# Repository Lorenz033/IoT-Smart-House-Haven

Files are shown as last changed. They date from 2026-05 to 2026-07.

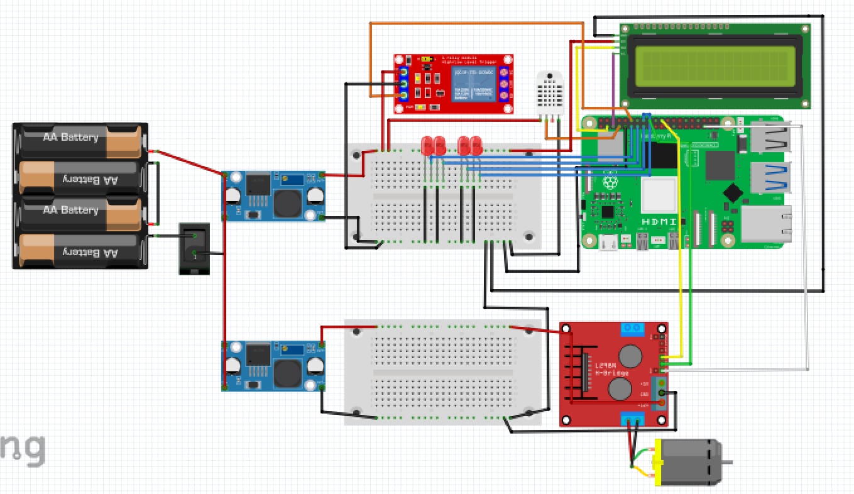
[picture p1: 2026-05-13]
schematic/d1bb4838-2788-41eb-9520-5f88e29ecf18.jpg

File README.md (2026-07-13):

# 📘 Smart Haven IoT System (Raspberry Pi + MQTT + MVC)

## 🧠 Overview

Smart Haven is an IoT-based automation system built using:

- Raspberry Pi 5
- MQTT communication
- Node-RED Dashboard
- Face Recognition (OpenCV + face_recognition)
- Voice Recognition (Vosk)
- LCD Display (I2C)
- GPIO Relay Control
- DC Motor Control (L298N + PWM)
- MVC software architecture

The system supports:
- Smart door access (face + voice authentication)
- Relay control (lock/unlock)
- DC motor speed control via Node-RED slider
- Scenario-based automation (Welcome / Leaving mode)

## Hardware pinout

All GPIO numbers below use **BCM numbering** (`GPIO.setmode(GPIO.BCM)`). The
physical-pin column refers to the Raspberry Pi's 40-pin header.

| Device / signal | BCM GPIO | Physical header pin | Direction / notes |
|---|---:|---:|---|
| DHT22 data | GPIO 4 | 7 | Input; temperature and humidity sensor |
| LED DO1 | GPIO 17 | 11 | Output |
| LED DO2 | GPIO 27 | 13 | Output |
| LED DO3 | GPIO 22 | 15 | Output |
| LED DO4 | GPIO 23 | 16 | Output |
| Relay / door lock control | GPIO 18 | 12 | Output; HIGH = unlock, LOW = lock |
| MG90S door-servo signal | GPIO 19 | 35 | PWM output |
| LED DO5 | GPIO 16 | 36 | Output |
| LED DO6 | GPIO 20 | 38 | Output |
| LED DO7 | GPIO 12 | 32 | Output |
| LED DO8 | GPIO 21 | 40 | Output |
| Flame-sensor digital output | GPIO 24 | 18 | Input; active LOW with internal pull-up |
| Smoke-sensor digital output | GPIO 26 | 37 | Input; active LOW with internal pull-up |
| Buzzer control | GPIO 25 | 22 | Output |
| L298N motor enable (ENA) | GPIO 13 | 33 | PWM output at 1 kHz |
| L298N motor direction (IN1) | GPIO 5 | 29 | Output |
| L298N motor direction (IN2) | GPIO 6 | 31 | Output |
| LCD I²C SDA | GPIO 2 / SDA1 | 3 | I²C bus 1 |
| LCD I²C SCL | GPIO 3 / SCL1 | 5 | I²C bus 1 |

The LCD is configured as a 16×2 PCF8574 I²C display at address `0x27` on I²C
bus 1. Connect each module's power and ground pins to a suitable supply and a
common Raspberry Pi ground. Do not power motors or a servo directly from a Pi
GPIO or 5 V rail unless the power budget has been verified; use an appropriate
external supply and retain the common ground.

---

Node-RED Dashboard
↓
MQTT Broker
↓
App Controller (Brain)
↓
────────────────────────
| Scenario Logic |
| Services Layer |
| Model (State) |
| View (LCD Display) |
────────────────────────
↓
Raspberry Pi GPIO / PWM

⚙️ Features
🔐 Smart Door System
Face recognition authentication
Voice command activation ("open")
Automatic unlock/lock via relay
📺 LCD Feedback
System status display
Welcome / Goodbye messages
Real-time feedback
📡 MQTT Communication
Topic	Function
WSA2025/DI1	Scenario trigger button
WSA2025/RELAY01	Manual relay control
WSA2025/MOTOR01	DC motor speed control

DC motor buttons should publish to `WSA2025/MOTOR01`:
- `50` for 50 percent speed
- `75` for 75 percent speed
- `100` for 100 percent speed
- `OFF` to stop the motor

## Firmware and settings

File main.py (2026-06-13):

# main.py
from services.mqtt_service import MQTTService
from services.gpio_service import GPIOService
from view.lcd_view import LCDView
from services.vision_service import VisionService
from services.voice_service import VoiceService
from services.sensor_service import SensorService
from model.environment_model import EnvironmentModel
from controller.app_controller import AppController

BROKER = "localhost"
PORT = 1883

TOPIC_DI1 = "WSA2025/DI1"
TOPIC_RELAY = "WSA2025/RELAY01"
TOPIC_DO1 = "WSA2025/DO1"
TOPIC_DO2 = "WSA2025/DO2"
TOPIC_DO3 = "WSA2025/DO3"
TOPIC_DO4 = "WSA2025/DO4"
TOPIC_DO5 = "WSA2025/DO5"
TOPIC_DO6 = "WSA2025/DO6"
TOPIC_DO7 = "WSA2025/DO7"
TOPIC_DO8 = "WSA2025/DO8"
TOPIC_MOTOR = "WSA2025/MOTOR01"
TOPIC_BUZZER = "WSA2025/BUZZER01"
TOPIC_DOOR = "WSA2025/DOOR01"
TOPIC_FIRE_STATUS = "WSA2025/FIRE_STATUS"
TOPIC_SMOKE_STATUS = "WSA2025/SMOKE_STATUS"



sensor = SensorService(pin=4)
environment = EnvironmentModel()

# =========================
# INIT COMPONENTS
# =========================
mqtt_service = MQTTService(BROKER, PORT)

gpio = GPIOService(
    pin=18,
    flame_pin=24,
    smoke_pin=26,
    buzzer_pin=25,
    servo_pin=19,
    flame_active_low=True,
    smoke_active_low=True
)

lcd = LCDView()

vision = VisionService(
    "/home/lorenz/iothings/models/manny.pkl"
)

# 🔥 FIX: NO mic_index anymore (auto-detect inside service)
voice = VoiceService(
    "/home/lorenz/iothings/models/vosk-model-small-en-us-0.15"
)

controller = AppController(
    mqtt_service.client,
    gpio,
    lcd,
    vision,
    voice,
    sensor,
    environment 
)


client = mqtt_service.connect(
    on_connect=lambda c, u, f, rc: c.subscribe([
        (TOPIC_DI1, 0),
        (TOPIC_RELAY, 0),
        (TOPIC_DO1, 0),
        (TOPIC_DO2, 0),
        (TOPIC_DO3, 0),
        (TOPIC_DO4, 0),
        (TOPIC_DO5, 0),
        (TOPIC_DO6, 0),
        (TOPIC_DO7, 0),
        (TOPIC_DO8, 0),
        (TOPIC_MOTOR, 0),
        (TOPIC_BUZZER, 0),
        (TOPIC_DOOR, 0)
    ]),
    on_message=controller.on_message,
    on_disconnect=lambda c, u, rc: print("Disconnected")
)

print("System running...")
client.loop_forever()

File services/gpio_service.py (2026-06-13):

import RPi.GPIO as GPIO
from gpiozero import AngularServo

class GPIOService:

    def __init__(
        self,
        pin=18,
        flame_pin=24,
        smoke_pin=26,
        buzzer_pin=25,
        servo_pin=19,
        flame_active_low=True,
        smoke_active_low=True
    ):

  
        self.pin = pin
        self.flame_pin = flame_pin
        self.smoke_pin = smoke_pin
        self.buzzer_pin = buzzer_pin
        self.servo_pin = servo_pin
        self.flame_active_low = flame_active_low
        self.smoke_active_low = smoke_active_low
        self.motor_speed = 0

  
        self.leds = {
            "DO1": 17,
            "DO2": 27,
            "DO3": 22,
            "DO4": 23,
            "DO5": 16,
            "DO6": 20,
            "DO7": 12,
            "DO8": 21
        }

        self.motor = {
            "ENA": 13,
            "IN1": 5,
            "IN2": 6
        }

        GPIO.setwarnings(False)
        GPIO.setmode(GPIO.BCM)

        # Relay
        GPIO.setup(self.pin, GPIO.OUT)
        GPIO.output(self.pin, GPIO.HIGH)

        # Flame sensor and buzzer
        flame_pull_mode = GPIO.PUD_UP if self.flame_active_low else GPIO.PUD_DOWN
        GPIO.setup(self.flame_pin, GPIO.IN, pull_up_down=flame_pull_mode)

        # Smoke sensor
        smoke_pull_mode = GPIO.PUD_UP if self.smoke_active_low else GPIO.PUD_DOWN
        GPIO.setup(self.smoke_pin, GPIO.IN, pull_up_down=smoke_pull_mode)

        GPIO.setup(self.buzzer_pin, GPIO.OUT)
        GPIO.output(self.buzzer_pin, GPIO.LOW)

        # LEDs
        for led_pin in self.leds.values():
            GPIO.setup(led_pin, GPIO.OUT)
            GPIO.output(led_pin, GPIO.LOW)

        # DC Motor with L298N
        GPIO.setup(self.motor["ENA"], GPIO.OUT)
        GPIO.setup(self.motor["IN1"], GPIO.OUT)
        GPIO.setup(self.motor["IN2"], GPIO.OUT)

        GPIO.output(self.motor["IN1"], GPIO.LOW)
        GPIO.output(self.motor["IN2"], GPIO.LOW)

        self.motor_pwm = GPIO.PWM(self.motor["ENA"], 1000)
        self.motor_pwm.start(0)

        # MG90S door servo
        self.door_servo = AngularServo(
            self.servo_pin,
            min_pulse_width=0.0006,
            max_pulse_width=0.0023
        )
        self.close_door()

  
    def lock(self):
        GPIO.output(self.pin, GPIO.LOW)

    def unlock(self):
        GPIO.output(self.pin, GPIO.HIGH)

    def is_flame_detected(self):
        flame_state = GPIO.input(self.flame_pin)

        if self.flame_active_low:
            return flame_state == GPIO.LOW
        return flame_state == GPIO.HIGH

    def is_smoke_detected(self):
        smoke_state = GPIO.input(self.smoke_pin)

        if self.smoke_active_low:
            return smoke_state == GPIO.LOW
        return smoke_state == GPIO.HIGH

    def buzzer_on(self):
        GPIO.output(self.buzzer_pin, GPIO.HIGH)

    def buzzer_off(self):
        GPIO.output(self.buzzer_pin, GPIO.LOW)

    def open_door(self):
        self.door_servo.angle = 90

    def close_door(self):
        self.door_servo.angle = -1

    def set_door(self, state):
        if state in ("ON", "OPEN"):
            self.open_door()
        else:
            self.close_door()

  
    def set_led(self, led, state):

        pin = self.leds.get(led)

        if pin is None:
            return
        GPIO.output(pin, GPIO.HIGH if state == "ON" else GPIO.LOW)

    def set_motor_speed(self, speed):

        try:
            speed = int(speed)
        except (TypeError, ValueError):
            return

        if speed not in (50, 75, 100):
            return

        self.motor_speed = speed
        GPIO.output(self.motor["IN1"], GPIO.HIGH)
        GPIO.output(self.motor["IN2"], GPIO.LOW)
        self.motor_pwm.ChangeDutyCycle(speed)

    def stop_motor(self):
        self.motor_speed = 0
        self.motor_pwm.ChangeDutyCycle(0)
        GPIO.output(self.motor["IN1"], GPIO.LOW)
        GPIO.output(self.motor["IN2"], GPIO.LOW)

    def all_off(self):
        self.lock()
        self.close_door()
        self.stop_motor()
        self.buzzer_off()

        for led in self.leds:
            self.set_led(led, "OFF")

    def all_on(self):
        self.unlock()
        self.open_door()
        self.set_motor_speed(50)
        self.buzzer_off()

        for led in self.leds:
            self.set_led(led, "ON")

    def cleanup(self):
        self.all_off()
        self.motor_pwm.stop()
        self.door_servo.close()
        GPIO.cleanup()

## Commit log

2026-05-09 updated with temperature and humidity
2026-05-09 updated syntax with DHT22 sensor
2026-05-13 added schematic diagram 5V Buck converter to sensors and 9V to Motor Driver
    [Smart_Haven.fzz]
2026-05-15 added red node flow
2026-05-20 added motor control
2026-06-06 fix bug camera mic index
    [gpio_service.py, main.py, voice_service.py]
2026-06-06 fix bug, wherein after goodbye mode, actuators still working and lights
2026-06-06 fix printing LCD
2026-06-10 added 2 led lights
2026-06-10 added 2 led lights for windows
2026-06-13 Master Lock Relay Added
2026-06-13 Master Lock BUG fixed
    [gpio_service.py]
2026-06-13 Servo Door Added
